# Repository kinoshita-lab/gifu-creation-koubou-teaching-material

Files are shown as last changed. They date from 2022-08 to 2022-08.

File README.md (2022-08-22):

# gifu-creation-koubou-teaching-material
こちらは、オンラインワークショップ 岐阜クリエーション工房2022 2. 自分の電子楽器をデザインしよう！
https://sites.google.com/iamas.ac.jp/gifu-creation-workshop/2022?authuser=0#h.r4l3rx4b2rmy
で配布した教材のリポジトリです。

## 教材基板ハードウェアの設計図(pdf)
- [ベースボードの回路図](https://github.com/kinoshita-lab/gifu-creation-koubou-teaching-material/blob/main/hardware/base-pcb/gifu-creation-koubou-teaching-material-schematics.pdf)
- [ベースボードの基板](https://github.com/kinoshita-lab/gifu-creation-koubou-teaching-material/blob/main/hardware/base-pcb/gifu-creation-koubou-teaching-material-pcb.pdf)

- [フィルターの回路図](https://github.com/kinoshita-lab/gifu-creation-koubou-teaching-material/blob/main/hardware/vcf-13700/vcf-13700-schematics.pdf)
- [フィルターの基板](https://github.com/kinoshita-lab/gifu-creation-koubou-teaching-material/blob/main/hardware/vcf-13700/vcf-13700-pcb.pdf)

- [ディレイの回路図](https://github.com/kinoshita-lab/gifu-creation-koubou-teaching-material/blob/main/hardware/PT2399delay/PT2399delay-schematics.pdf)
- [ディレイの基板](https://github.com/kinoshita-lab/gifu-creation-koubou-teaching-material/blob/main/hardware/PT2399delay/PT2399delay-pcb.pdf)

## マイコンのソフト
[Platform IO](https://platformio.org/) という開発環境を使っています。
- [ライブラリを含んだ全体](https://github.com/kinoshita-lab/gifu-creation-koubou-teaching-material/tree/main/software/gifu-creation-koubou-teathing-material-esp32)
- [一番重要な内容が書いてあるファイル](https://github.com/kinoshita-lab/gifu-creation-koubou-teaching-material/blob/main/software/gifu-creation-koubou-teathing-material-esp32/src/main.cpp)

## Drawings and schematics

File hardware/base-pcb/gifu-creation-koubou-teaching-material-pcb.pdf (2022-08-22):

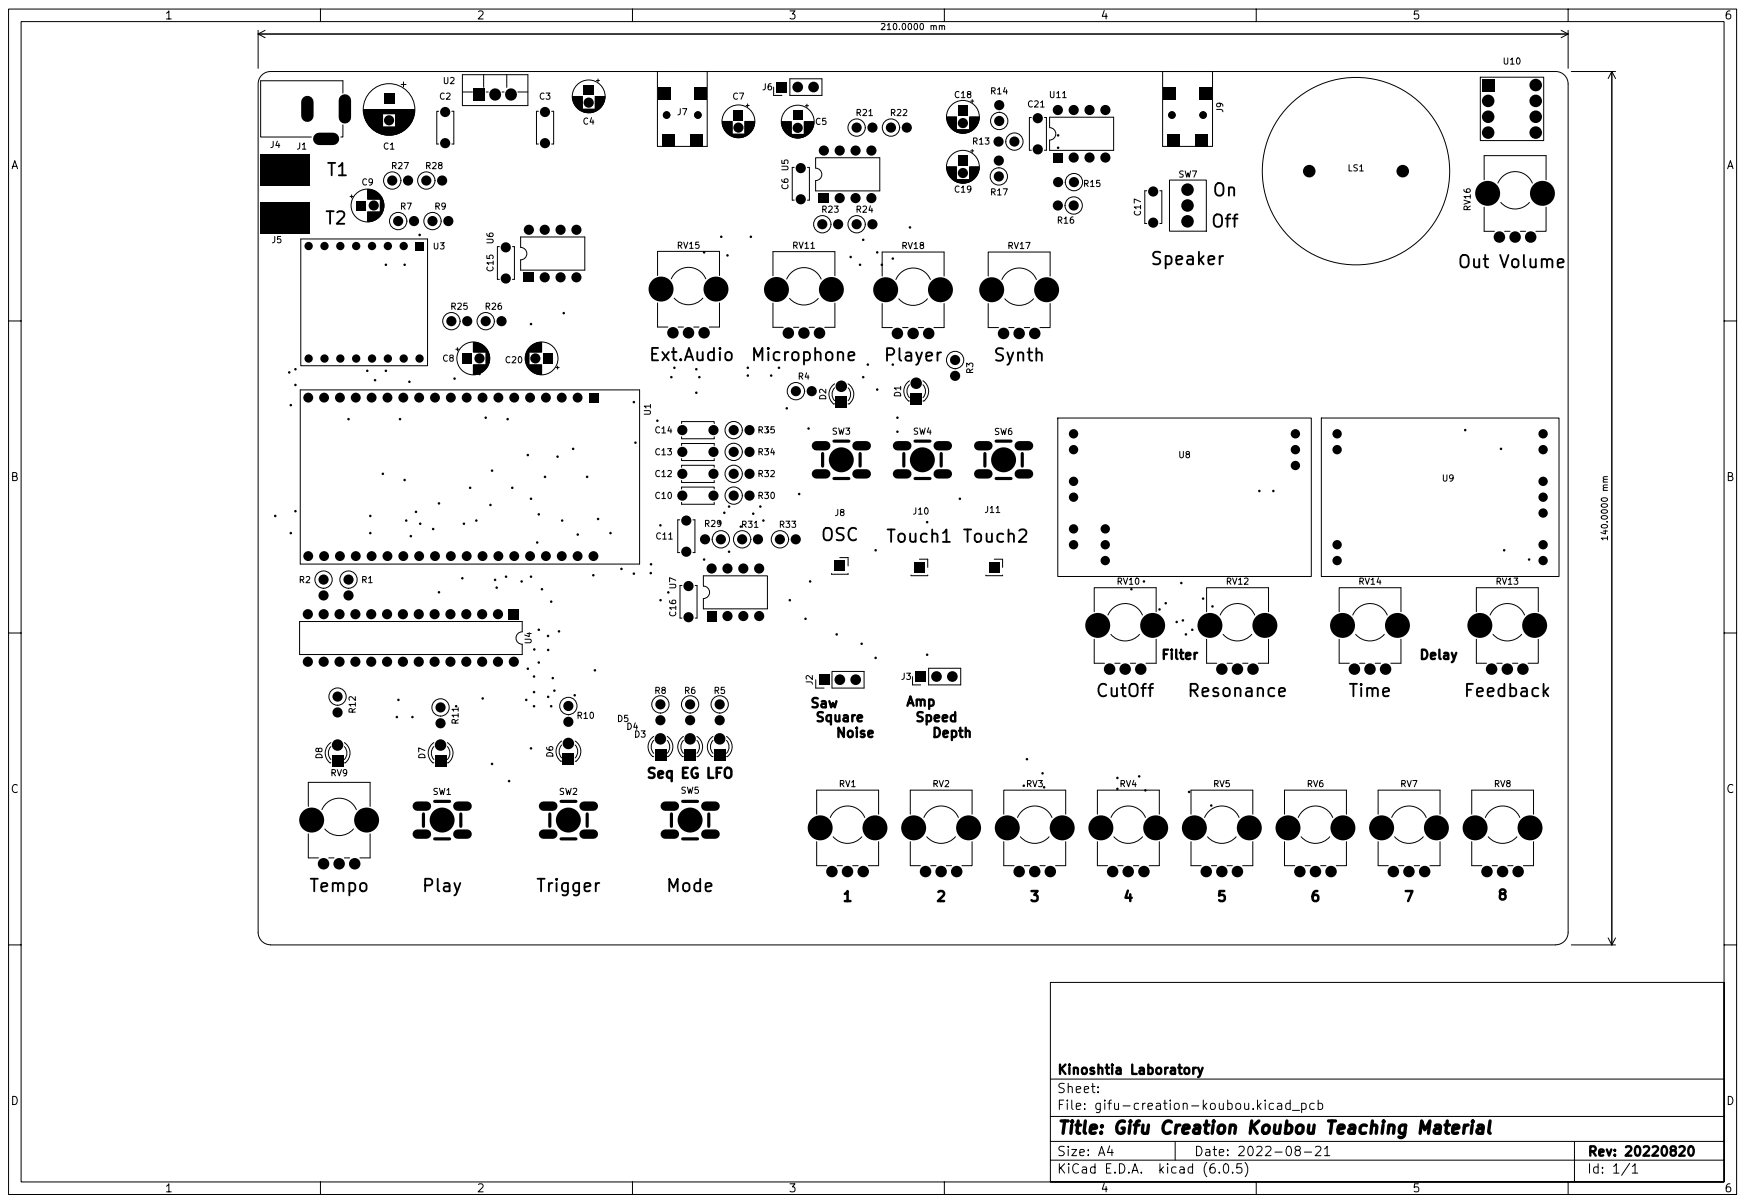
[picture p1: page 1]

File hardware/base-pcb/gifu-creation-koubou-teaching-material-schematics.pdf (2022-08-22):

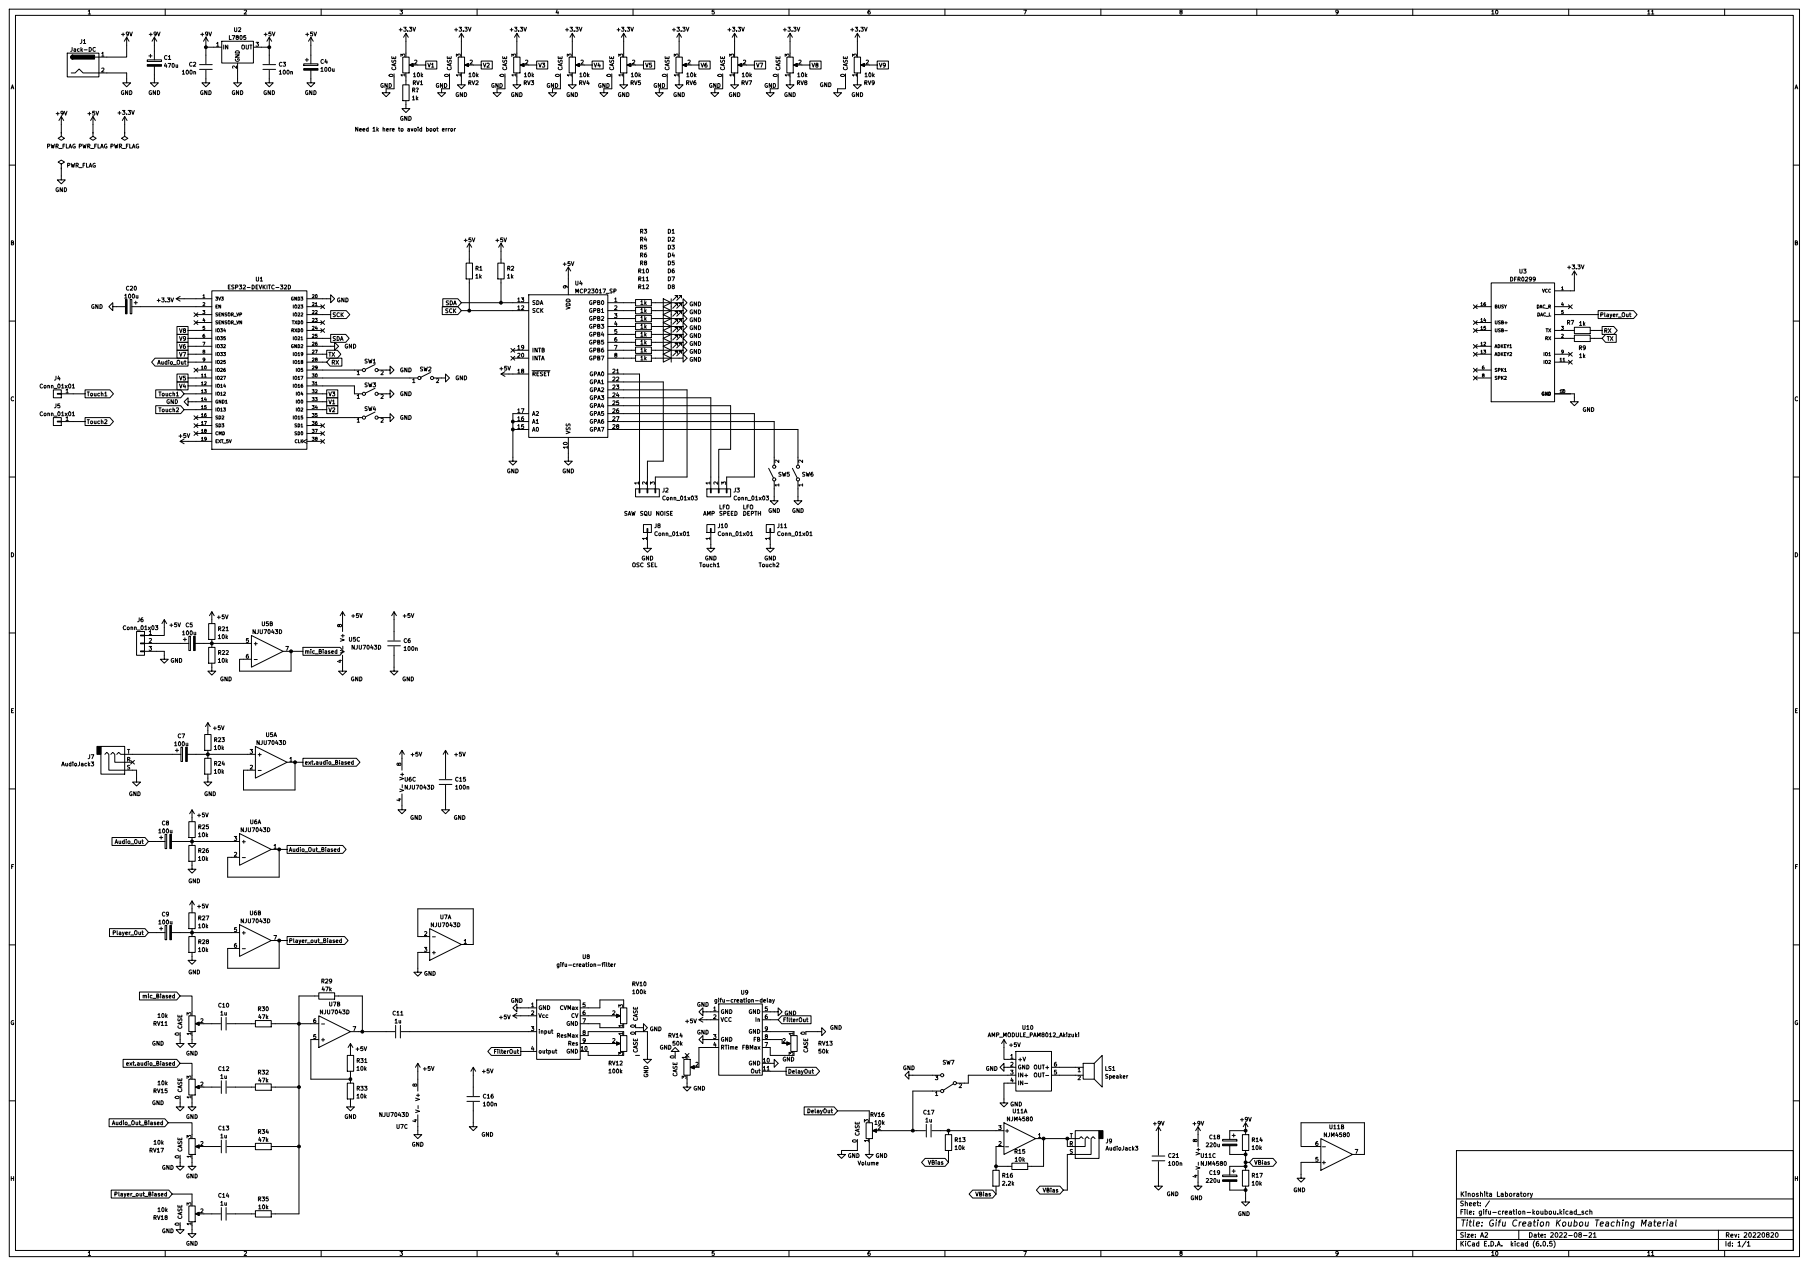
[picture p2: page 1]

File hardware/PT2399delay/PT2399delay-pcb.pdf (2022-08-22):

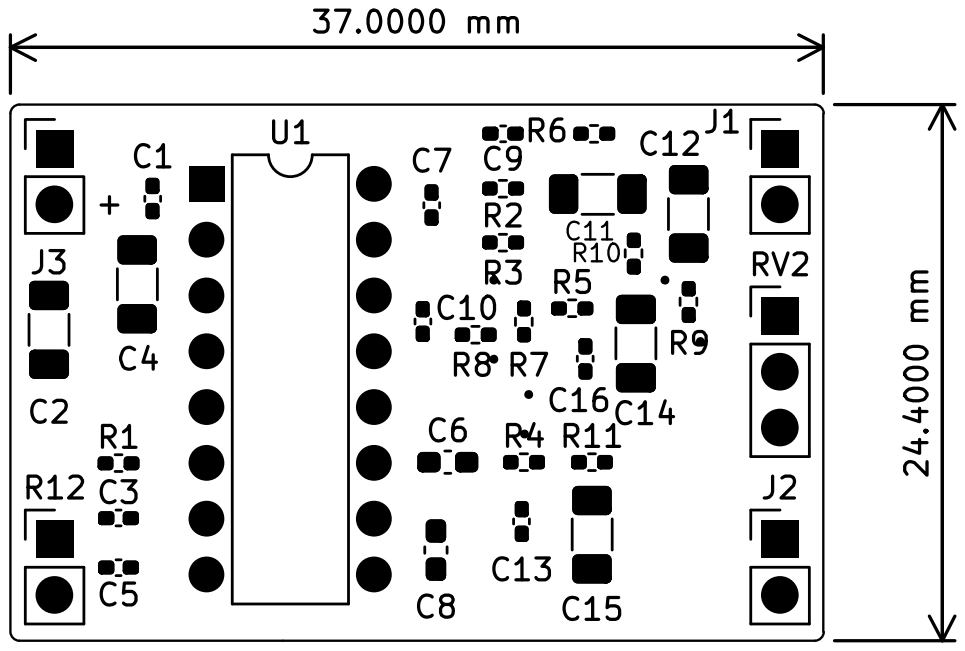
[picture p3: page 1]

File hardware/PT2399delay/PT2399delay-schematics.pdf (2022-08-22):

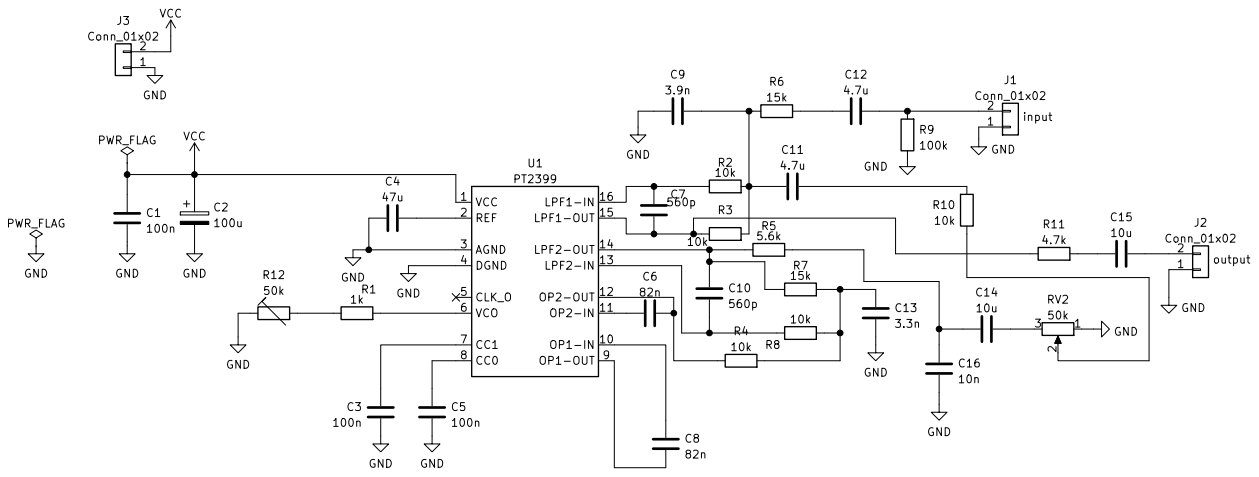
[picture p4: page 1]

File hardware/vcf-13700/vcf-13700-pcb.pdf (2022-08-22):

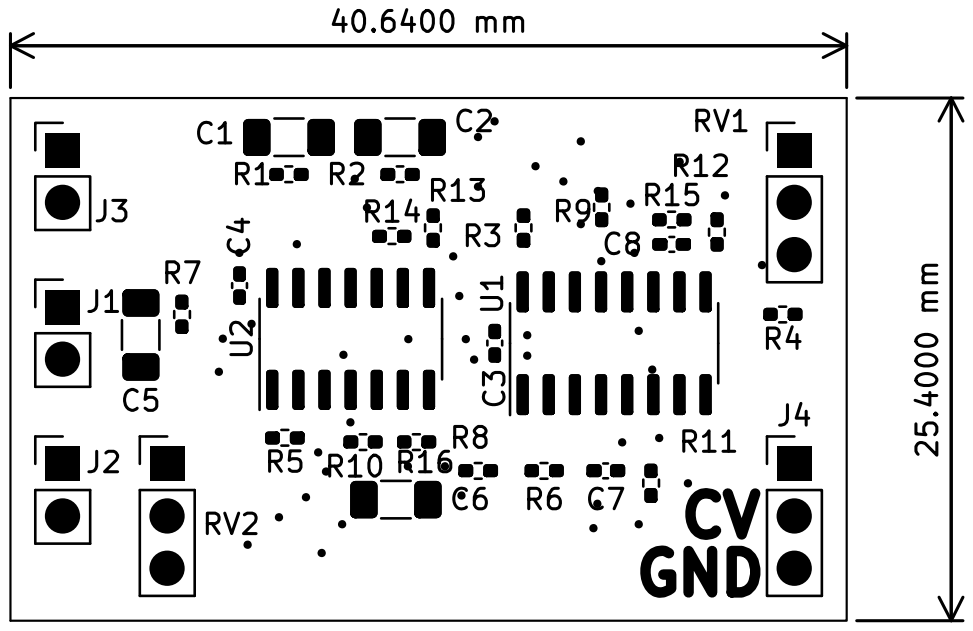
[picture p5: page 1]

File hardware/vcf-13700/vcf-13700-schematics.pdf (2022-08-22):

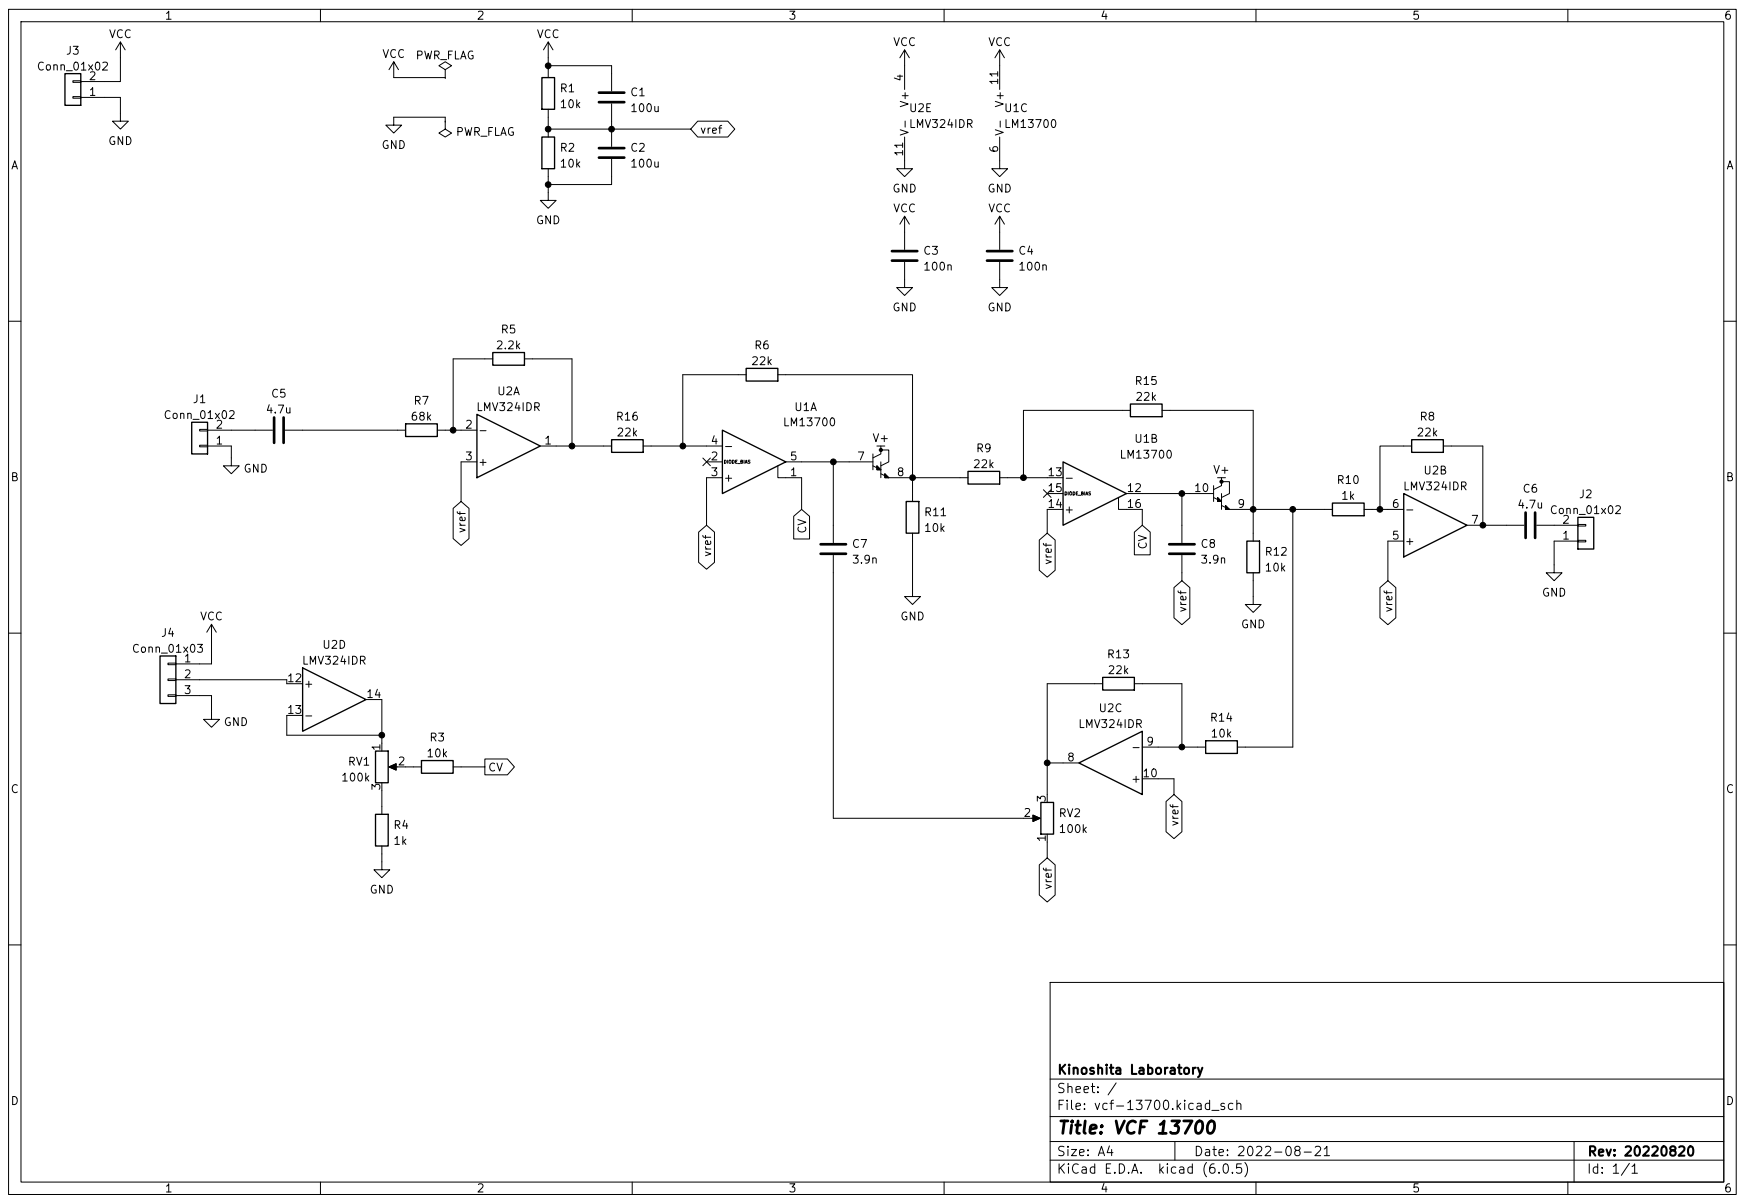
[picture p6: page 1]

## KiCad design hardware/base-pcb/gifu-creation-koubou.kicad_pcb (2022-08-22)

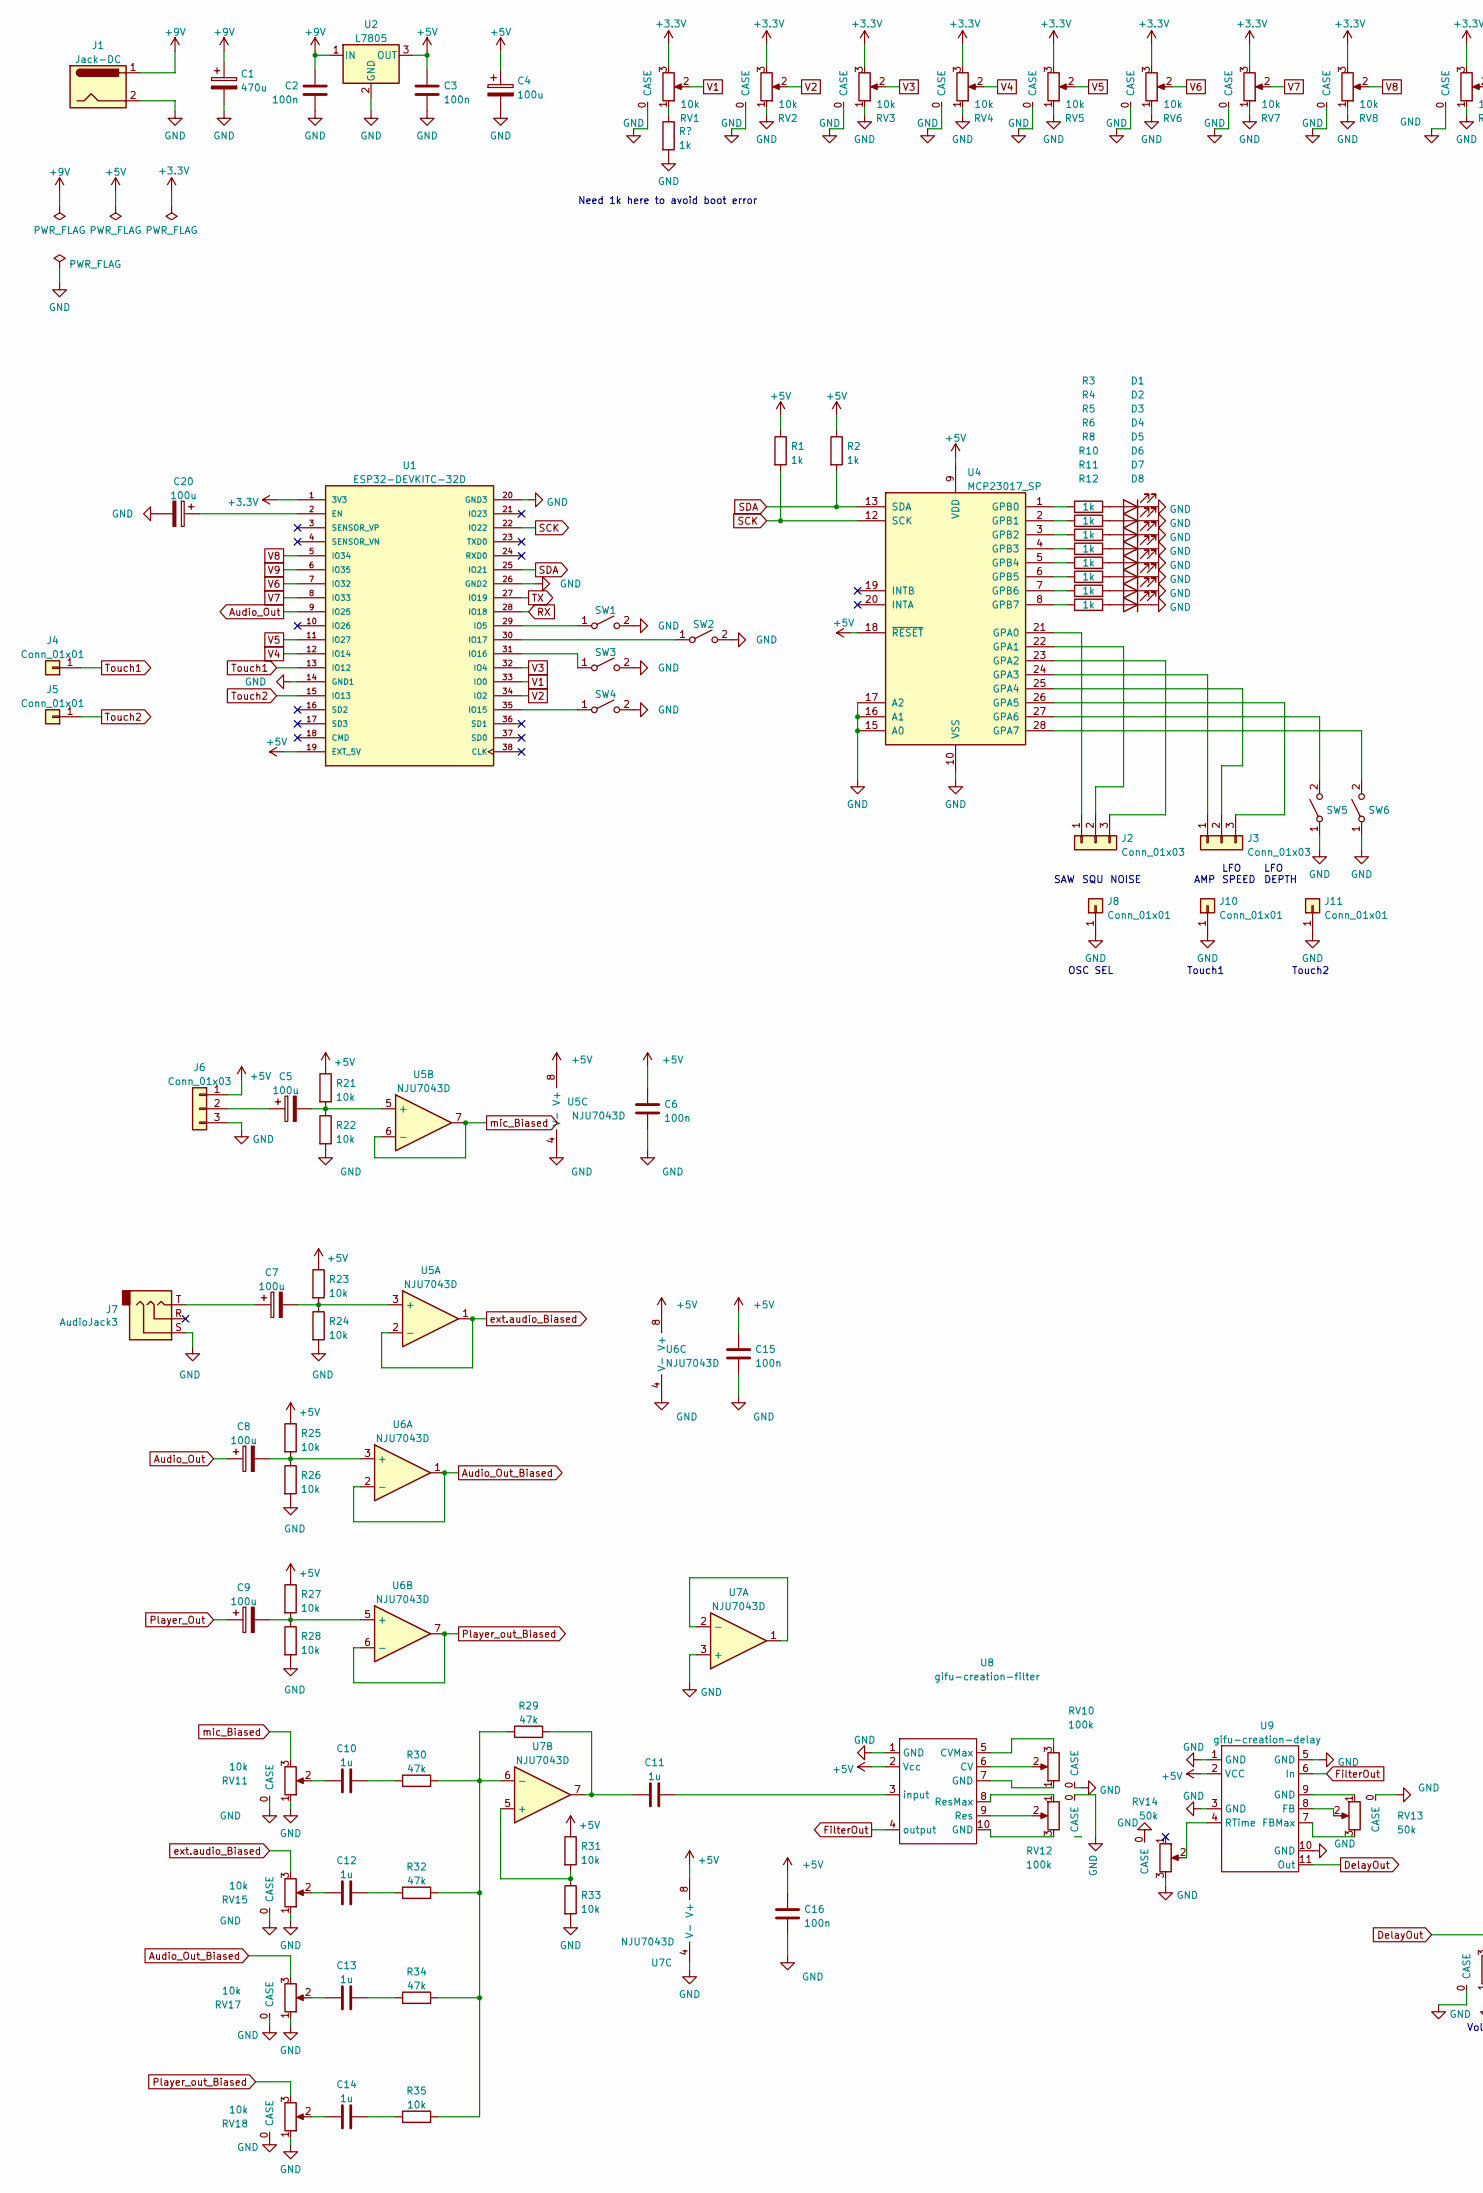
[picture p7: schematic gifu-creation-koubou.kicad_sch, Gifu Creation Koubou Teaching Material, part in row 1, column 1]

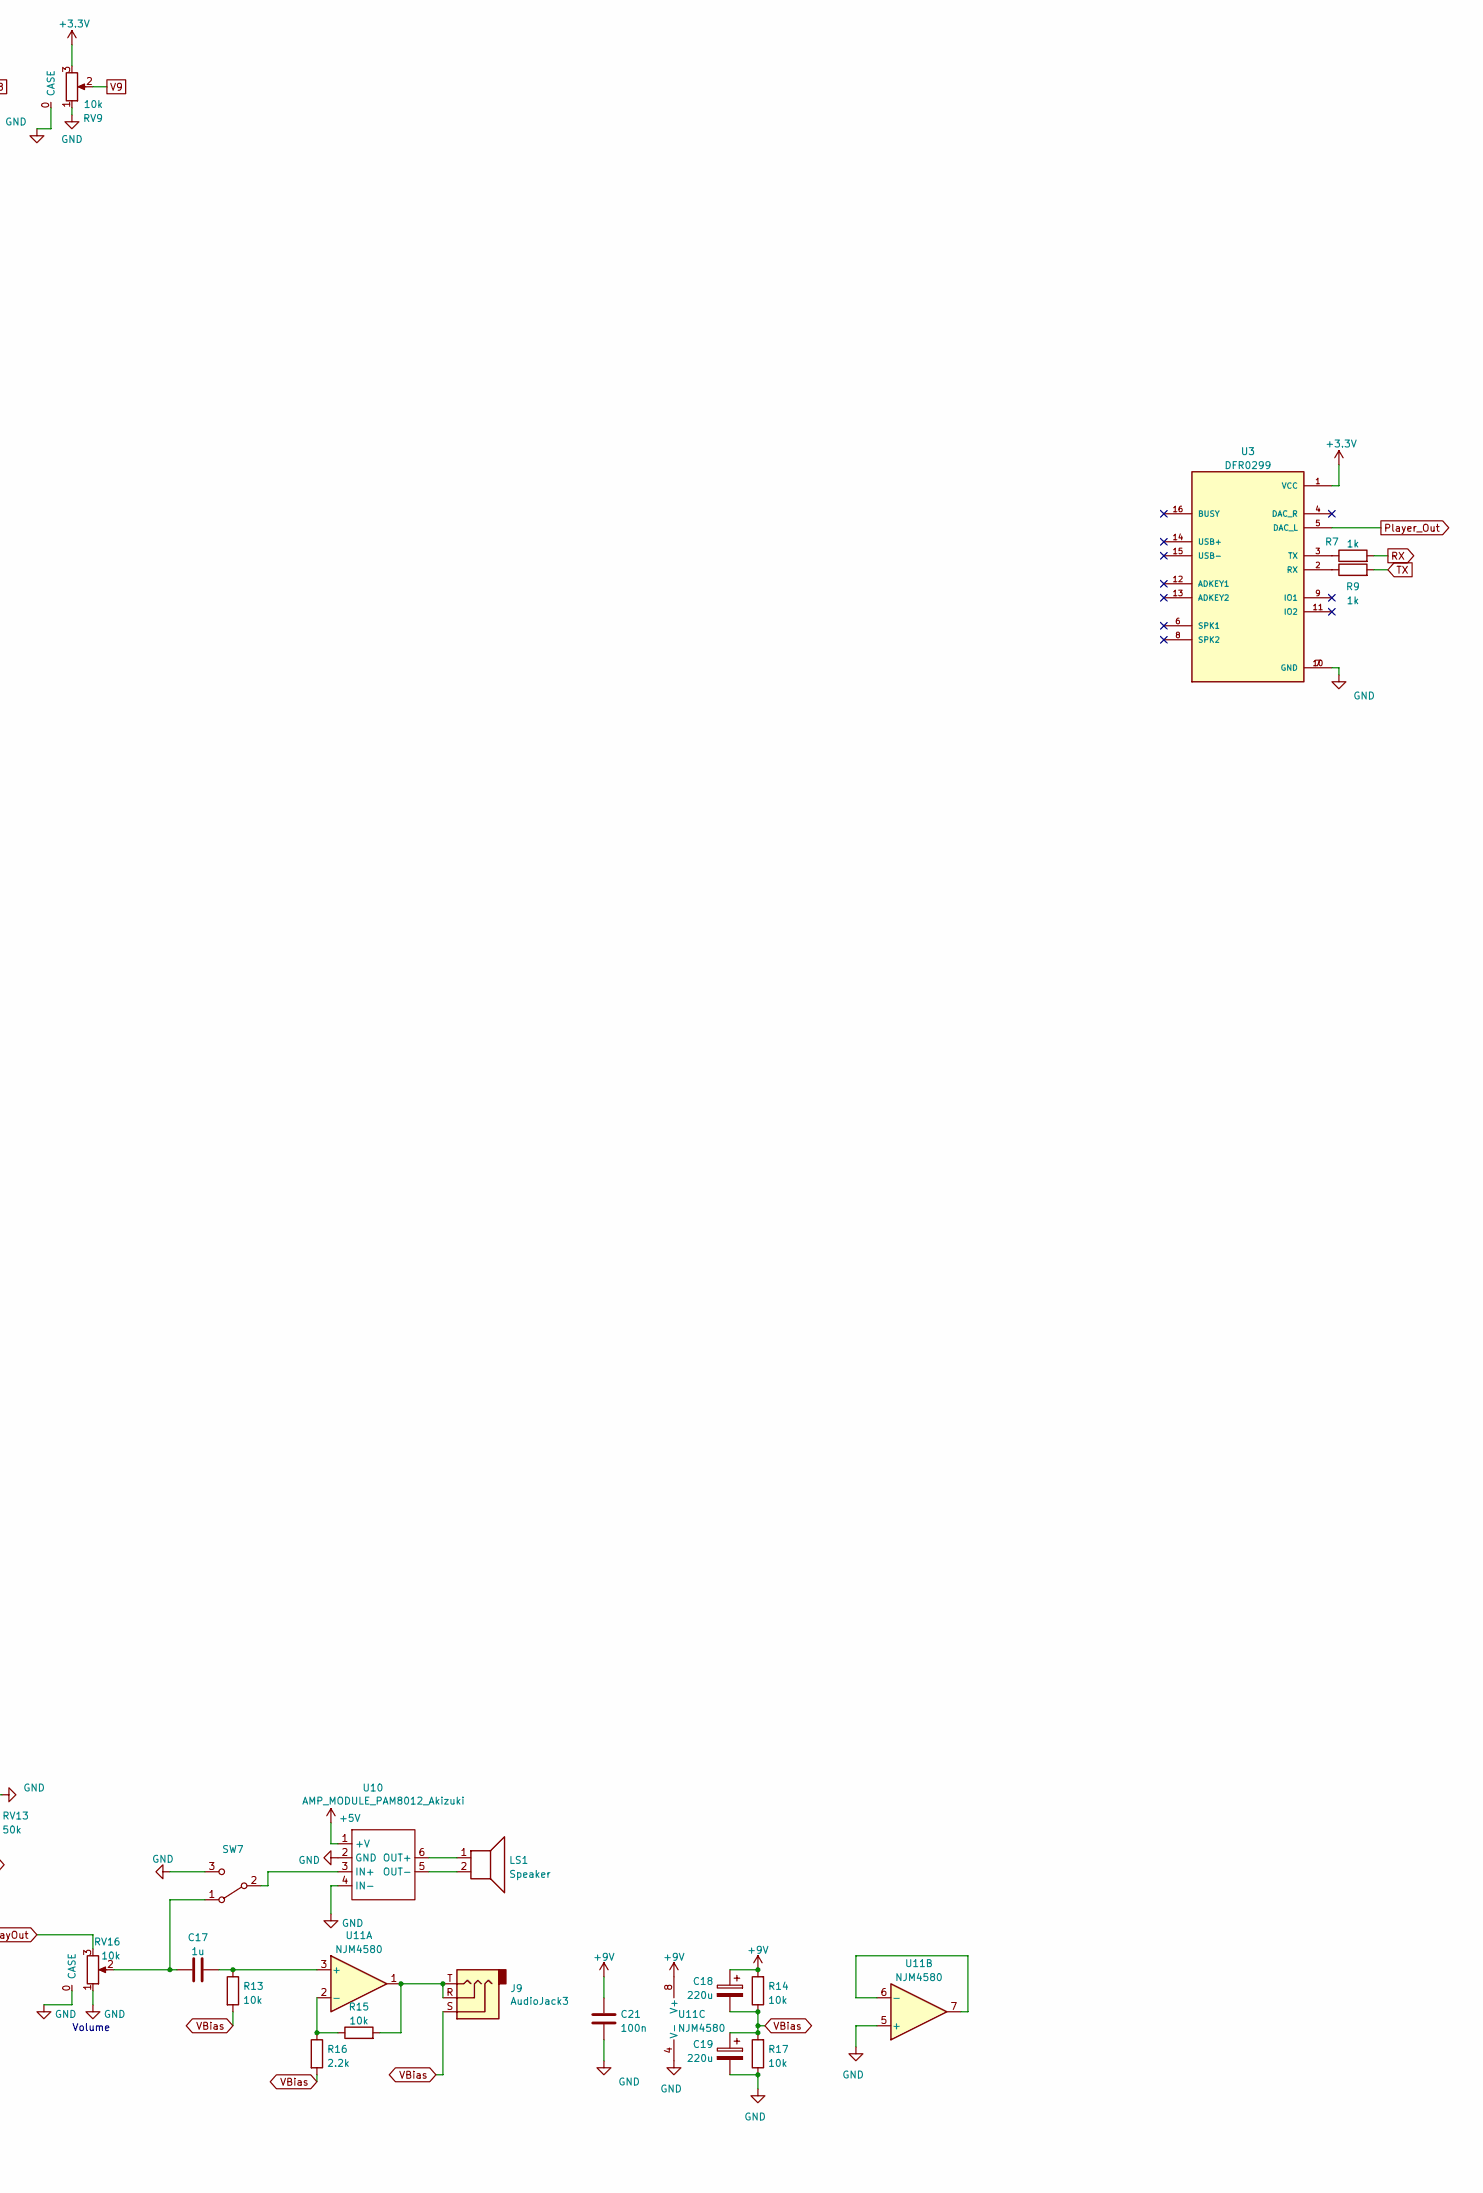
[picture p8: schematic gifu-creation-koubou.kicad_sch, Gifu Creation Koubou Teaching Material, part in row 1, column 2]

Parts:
C1: 470u; CP_Radial_D8.0mm_P3.50mm
C2, C3, C6, C15, C16, C21: 100n; C_Disc_D5.0mm_W2.5mm_P5.00mm
C4, C5, C7, C8, C9, C20: 100u; CP_Radial_D5.0mm_P2.00mm
C10, C11, C12, C13, C14, C17: 1u; C_Disc_D5.0mm_W2.5mm_P5.00mm
C18, C19: 220u; CP_Radial_D5.0mm_P2.00mm
D1, D2, D3, D4, D5, D6, D7, D8: LED; LED_D3.0mm
J1: Jack-DC; DCJ3P-14.2X11.0X9.0MM
J2, J3, J6: Conn_01x03; PinHeader_1x03_P2.54mm_Vertical
J4, J5: Conn_01x01; touch_electrode
J7, J9: AudioJack3; 3.5mm_Stereo_TRS_PJ-3210-4A_and_ST-005-G; LCSC C136686
J8, J10, J11: Conn_01x01; PinSocket_1x01_P2.54mm_Vertical
LS1: Speaker; Speaker_UGSM30B-8-01
R1, R2, R3, R4, R5, R6, R7, R8, R9, R10, R11, R12: 1k; R_Axial_DIN0207_L6.3mm_D2.5mm_P2.54mm_Vertical
R13, R14, R15, R17, R21, R22, R23, R24, R25, R26, R27, R28, R31, R33, R35: 10k; R_Axial_DIN0207_L6.3mm_D2.5mm_P2.54mm_Vertical
R16: 2.2k; R_Axial_DIN0207_L6.3mm_D2.5mm_P2.54mm_Vertical
R29, R30, R32, R34: 47k; R_Axial_DIN0207_L6.3mm_D2.5mm_P2.54mm_Vertical
RV1, RV2, RV3, RV4, RV5, RV6, RV7, RV8, RV9, RV11, RV15, RV16, RV17, RV18: 10k; Potentiometer_Alps_RK09K_Horizontal_CORRECTED
RV10, RV12: 100k; Potentiometer_Alps_RK09K_Horizontal_CORRECTED
RV13, RV14: 50k; Potentiometer_Alps_RK09K_Horizontal_CORRECTED
SW1, SW2, SW3, SW4, SW5, SW6: SW_SPST; SW_Tactile_6mm_x_6mm_Futsuuno_Akizuki_nadoniaruyatsu
SW7: SW_SPDT; Switch_Toggle_PCB_Mount_Akizuki_2MS1-T1-B4-M2-Q-E
U1: ESP32-DEVKITC-32D; MODULE_ESP32-DEVKITC-32D; PARTREV 4
U2: L7805; TO-220F-3_Vertical
U3: DFR0299; MODULE_DFR0299
U4: MCP23017_SP; DIP-28_W7.62mm
U5, U6, U7: NJU7043D; DIP-8_W7.62mm
U8: gifu-creation-filter; filter_13700
U9: gifu-creation-delay; delay
U10: AMP_MODULE_PAM8012_Akizuki; AMP_Module_PAM8012_Akizuki
U11: NJM4580; DIP-8_W7.62mm

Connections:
+3V3: RV1.3, RV2.3, RV3.3, RV4.3, RV5.3, RV6.3, RV7.3, RV8.3, RV9.3, U1.1 (3V3), U3.1 (VCC)
+5V: C3.1, C4.1, C6.1, C15.1, C16.1, J6.1, R1.1, R2.1, R21.1, R23.1, R25.1, R27.1, R31.1, U1.19 (EXT_5V), U2.3 (OUT), U4.9 (VDD), U4.18 (~RESET), U5.8 (V+), U6.8 (V+), U7.8 (V+), U8.2 (Vcc), U9.2 (VCC), U10.1 (+V)
+9V: C1.1, C2.1, C18.1, C21.1, J1.1, R14.2, U2.1 (IN), U11.8 (V+)
Audio_Out: C8.1, U1.9 (IO25)
Audio_Out_Biased: RV17.3, U6.1, U6.2 (-)
DelayOut: RV16.3, U9.11 (Out)
FilterOut: U8.4 (output), U9.6 (In)
GND: C1.2, C2.2, C3.2, C4.2, C6.2, C15.2, C16.2, C19.2, C20.2, C21.2, D1.1 (K), D2.1 (K), D3.1 (K), D4.1 (K), D5.1 (K), D6.1 (K), D7.1 (K), D8.1 (K), J1.2, J6.3, J7.S, J8.1, J10.1, J11.1, R17.1, R22.2, R24.2, R26.2, R28.2, R33.2, RV1.0 (CASE), RV1.1, RV2.0 (CASE), RV2.1, RV3.0 (CASE), RV3.1, RV4.0 (CASE), RV4.1, RV5.0 (CASE), RV5.1, RV6.0 (CASE), RV6.1, RV7.0 (CASE), RV7.1, RV8.0 (CASE), RV8.1, RV9.0 (CASE), RV9.1, RV10.0 (CASE), RV11.0 (CASE), RV11.1, RV12.0 (CASE), RV13.0 (CASE), RV14.0 (CASE), RV14.3, RV15.0 (CASE), RV15.1, RV16.0 (CASE), RV16.1, RV17.0 (CASE), RV17.1, RV18.0 (CASE), RV18.1, SW1.2 (B), SW2.2 (B), SW3.2 (B), SW4.2 (B), SW5.1 (A), SW6.1 (A), SW7.3 (C), U1.14 (GND1), U1.20 (GND3), U1.26 (GND2), U2.2 (GND), U3.7 (GND), U3.10 (GND), U4.10 (VSS), U4.15 (A0), U4.16 (A1), U4.17 (A2), U5.4 (V-), U6.4 (V-), U7.3 (+), U7.4 (V-), U8.1 (GND), U9.1 (GND), U9.3 (GND), U9.5 (GND), U9.10 (GND), U10.2 (GND), U10.4 (IN-), U11.4 (V-), U11.5 (+)
unnamed: C5.1, J6.2
unnamed: C5.2, R21.2, R22.1, U5.5 (+)
unnamed: C7.1, J7.T
unnamed: C7.2, R23.2, R24.1, U5.3 (+)
unnamed: C8.2, R25.2, R26.1, U6.3 (+)
unnamed: C9.2, R27.2, R28.1, U6.5 (+)
unnamed: C10.1, RV11.2
unnamed: C10.2, R30.1
unnamed: C11.1, R29.2, U7.7
unnamed: C11.2, U8.3 (input)
unnamed: C12.1, RV15.2
unnamed: C12.2, R32.1
unnamed: C13.1, RV17.2
unnamed: C13.2, R34.1
unnamed: C14.1, RV18.2
unnamed: C14.2, R35.1
unnamed: C17.1, RV16.2, SW7.1 (A)
unnamed: C17.2, R13.1, U11.3 (+)
unnamed: D1.2 (A), R3.2
unnamed: D2.2 (A), R4.2
unnamed: D3.2 (A), R5.2
unnamed: D4.2 (A), R6.2
unnamed: D5.2 (A), R8.2
unnamed: D6.2 (A), R10.2
unnamed: D7.2 (A), R11.2
unnamed: D8.2 (A), R12.2
unnamed: J2.1, U4.21 (GPA0)
unnamed: J2.2, U4.22 (GPA1)
unnamed: J2.3, U4.23 (GPA2)
unnamed: J3.1, U4.24 (GPA3)
unnamed: J3.2, U4.25 (GPA4)
unnamed: J3.3, U4.26 (GPA5)
unnamed: J9.R, J9.T, R15.2, U11.1
unnamed: LS1.1, U10.6 (OUT+)
unnamed: LS1.2, U10.5 (OUT-)
unnamed: R3.1, U4.1 (GPB0)
unnamed: R4.1, U4.2 (GPB1)
unnamed: R5.1, U4.3 (GPB2)
unnamed: R6.1, U4.4 (GPB3)
unnamed: R7.1, U3.3 (TX)
unnamed: R8.1, U4.5 (GPB4)
unnamed: R9.1, U3.2 (RX)
unnamed: R10.1, U4.6 (GPB5)
unnamed: R11.1, U4.7 (GPB6)
unnamed: R12.1, U4.8 (GPB7)
unnamed: R15.1, R16.1, U11.2 (-)
unnamed: R29.1, R30.2, R32.2, R34.2, R35.2, U7.6 (-)
unnamed: R31.2, R33.1, U7.5 (+)
unnamed: RV10.1, U8.7 (GND)
unnamed: RV10.2, U8.6 (CV)
unnamed: RV10.3, U8.5 (CVMax)
unnamed: RV12.1, U8.8 (ResMax)
unnamed: RV12.2, U8.9 (Res)
unnamed: RV12.3, U8.10 (GND)
unnamed: RV13.1, U9.9 (GND)
unnamed: RV13.2, U9.8 (FB)
unnamed: RV13.3, U9.7 (FBMax)
unnamed: RV14.2, U9.4 (RTime)
unnamed: SW1.1 (A), U1.29 (IO5)
unnamed: SW2.1 (A), U1.30 (IO17)
unnamed: SW3.1 (A), U1.31 (IO16)
unnamed: SW4.1 (A), U1.35 (IO15)
unnamed: SW5.2 (B), U4.27 (GPA6)
unnamed: SW6.2 (B), U4.28 (GPA7)
unnamed: SW7.2 (B), U10.3 (IN+)
unnamed: C20.1, U1.2 (EN)
unnamed: U7.1, U7.2 (-)
unnamed: U11.6 (-), U11.7
Player_Out: C9.1, U3.5 (DAC_L)
Player_out_Biased: RV18.3, U6.6 (-), U6.7
RX: R7.2, U1.28 (IO18)
SCK: R1.2, U1.22 (IO22), U4.12 (SCK)
SDA: R2.2, U1.25 (IO21), U4.13 (SDA)
TX: R9.2, U1.27 (IO19)
Touch1: J4.1, U1.13 (IO12)
Touch2: J5.1, U1.15 (IO13)
V1: RV1.2, U1.33 (IO0)
V2: RV2.2, U1.34 (IO2)
V3: RV3.2, U1.32 (IO4)
V4: RV4.2, U1.12 (IO14)
V5: RV5.2, U1.11 (IO27)
V6: RV6.2, U1.7 (IO32)
V7: RV7.2, U1.8 (IO33)
V8: RV8.2, U1.5 (IO34)
V9: RV9.2, U1.6 (IO35)
VBias: C18.2, C19.1, J9.S, R13.2, R14.1, R16.2, R17.2
ext.audio_Biased: RV15.3, U5.1, U5.2 (-)
mic_Biased: RV11.3, U5.6 (-), U5.7

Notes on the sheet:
AMP
LFO DEPTH
SQU
OSC SEL
Volume
Touch1
Touch2
Need 1k here to avoid boot error
SAW
NOISE
LFO SPEED

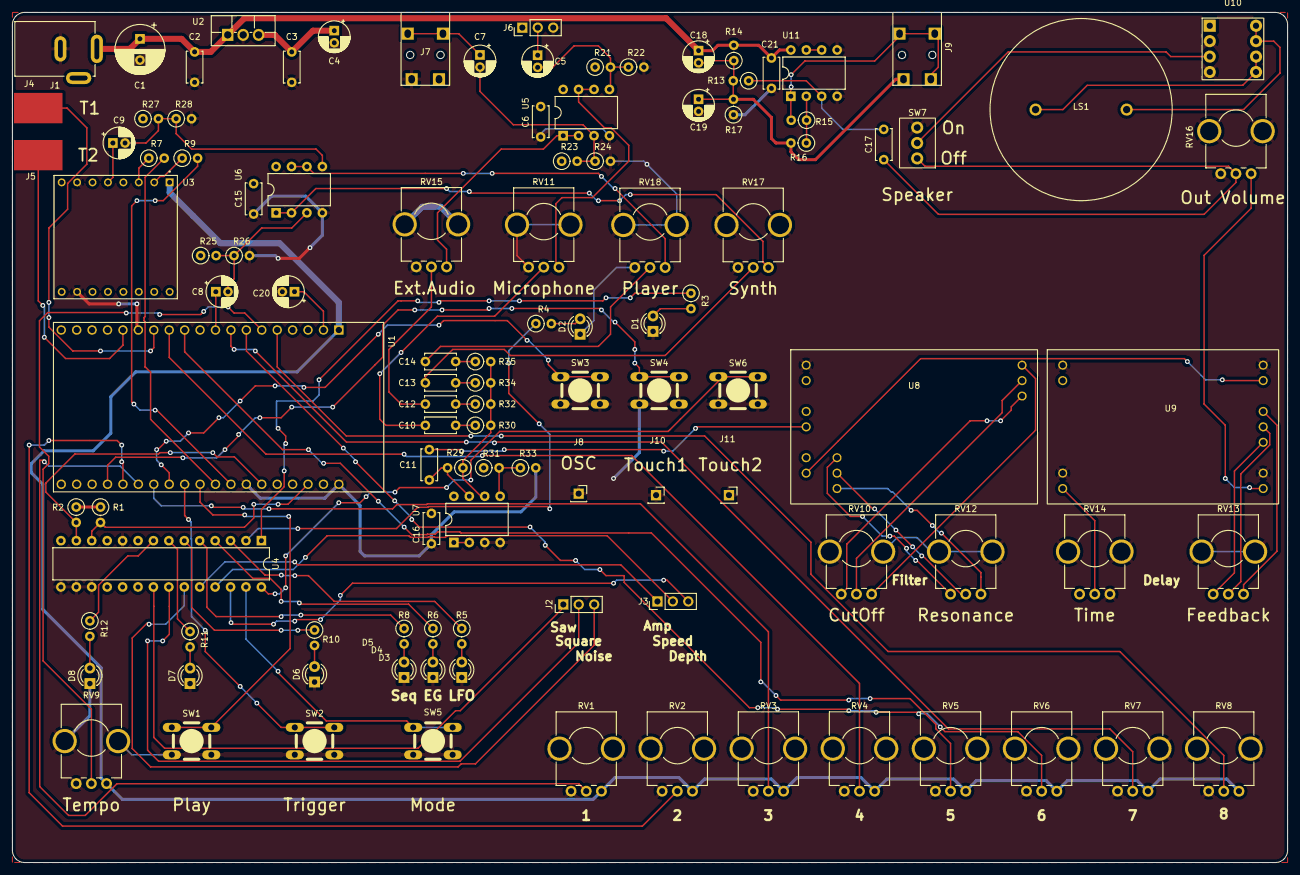
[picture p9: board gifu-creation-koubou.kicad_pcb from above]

Board: 2 copper layers, 210.0 x 140.0 mm, 109 parts (0 on the bottom side), 96 nets.

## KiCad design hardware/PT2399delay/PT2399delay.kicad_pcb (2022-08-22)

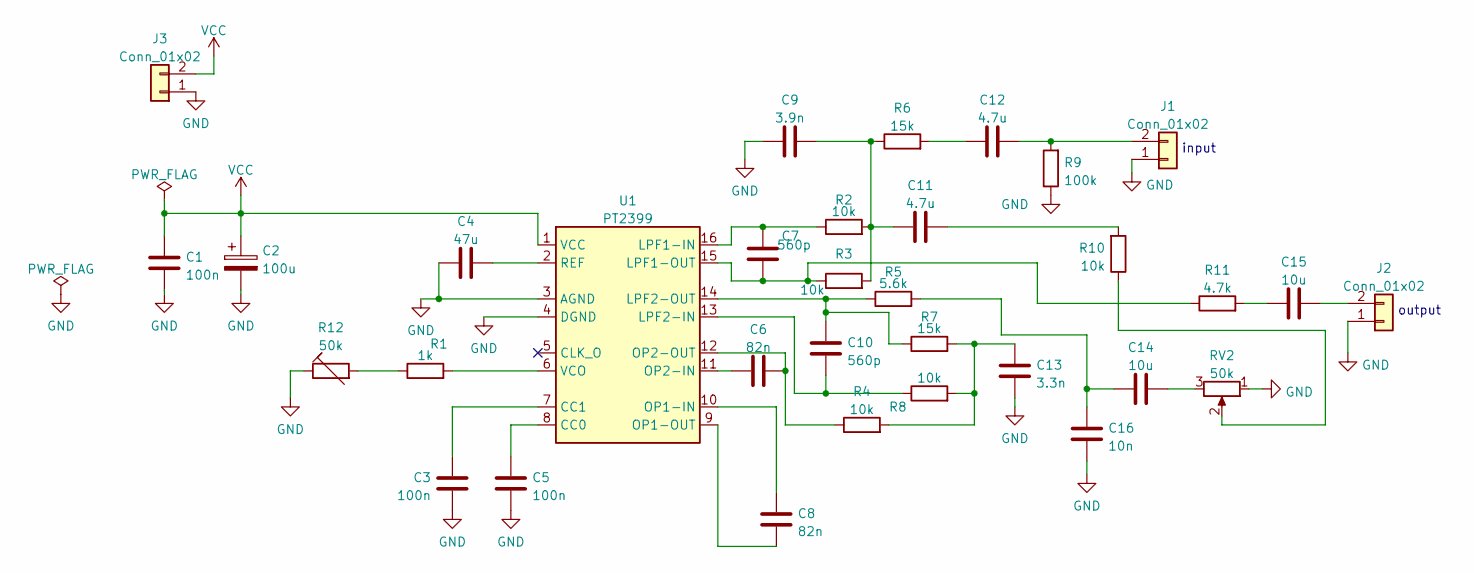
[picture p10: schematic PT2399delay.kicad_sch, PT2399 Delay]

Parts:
C1, C3, C5: 100n; C_0402_1005Metric_Pad0.74x0.62mm_HandSolder; LCSC C1525
C2: 100u; C_1206_3216Metric_Pad1.33x1.80mm_HandSolder; LCSC C312983
C4: 47u; C_1206_3216Metric_Pad1.33x1.80mm_HandSolder; LCSC C403725
C6, C8: 82n; C_0603_1608Metric_Pad1.08x0.95mm_HandSolder; LCSC C1951
C7, C10: 560p; C_0402_1005Metric_Pad0.74x0.62mm_HandSolder; LCSC C1539
C9: 3.9n; C_0402_1005Metric_Pad0.74x0.62mm_HandSolder; LCSC C45188
C11, C12: 4.7u; C_1206_3216Metric_Pad1.33x1.80mm_HandSolder; LCSC C29823
C13: 3.3n; C_0402_1005Metric_Pad0.74x0.62mm_HandSolder; LCSC C26404
C14: 10u; C_1206_3216Metric_Pad1.33x1.80mm_HandSolder; LCSC C13585
C15: 10u; C_1206_3216Metric_Pad1.33x1.80mm_HandSolder; LCSC C13585Copy
C16: 10n; C_0402_1005Metric_Pad0.74x0.62mm_HandSolder; LCSC C15195
J1, J2, J3: Conn_01x02; PinHeader_1x02_P2.54mm_Vertical
R1: 1k; R_0402_1005Metric_Pad0.72x0.64mm_HandSolder; LCSC C144789
R2, R3, R4, R8, R10: 10k; R_0402_1005Metric_Pad0.72x0.64mm_HandSolder; LCSC C25744
R5: 5.6k; R_0402_1005Metric_Pad0.72x0.64mm_HandSolder; LCSC C25908
R6, R7: 15k; R_0402_1005Metric_Pad0.72x0.64mm_HandSolder; LCSC C25756
R9: 100k; R_0402_1005Metric_Pad0.72x0.64mm_HandSolder; LCSC C25741
R11: 4.7k; R_0402_1005Metric_Pad0.72x0.64mm_HandSolder; LCSC C25900
R12: 50k; PinHeader_1x02_P2.54mm_Vertical
RV2: 50k; PinHeader_1x03_P2.54mm_Vertical
U1: PT2399; DIP-16_W7.62mm; LCSC C84963

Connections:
GND: C1.1, C2.2, C3.1, C4.1, C5.1, C9.2, C13.1, C16.2, J1.1, J2.1, J3.1, R9.1, R12.1, RV2.1, U1.3 (AGND), U1.4 (DGND)
unnamed: C3.2, U1.7 (CC1)
unnamed: C4.2, U1.2 (REF)
unnamed: C5.2, U1.8 (CC0)
unnamed: C6.1, U1.11 (OP2-IN)
unnamed: C6.2, R4.1, U1.12 (OP2-OUT)
unnamed: C7.1, R3.1, R11.1, U1.15 (LPF1-OUT)
unnamed: C7.2, R2.1, U1.16 (LPF1-IN)
unnamed: C8.1, U1.9 (OP1-OUT)
unnamed: C8.2, U1.10 (OP1-IN)
unnamed: C10.1, R8.1, U1.13 (LPF2-IN)
unnamed: C10.2, R5.1, R7.1, U1.14 (LPF2-OUT)
unnamed: C11.1, R10.2
unnamed: C9.1, C11.2, R2.2, R3.2, R6.1
unnamed: C12.1, J1.2, R9.2
unnamed: C12.2, R6.2
unnamed: C13.2, R4.2, R7.2, R8.2
unnamed: C14.1, RV2.3
unnamed: C14.2, C16.1, R5.2
unnamed: C15.1, J2.2
unnamed: C15.2, R11.2
unnamed: R1.1, R12.2
unnamed: R1.2, U1.6 (VCO)
unnamed: R10.1, RV2.2
VCC: C1.2, C2.1, J3.2, U1.1 (VCC)

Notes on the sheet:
input
output

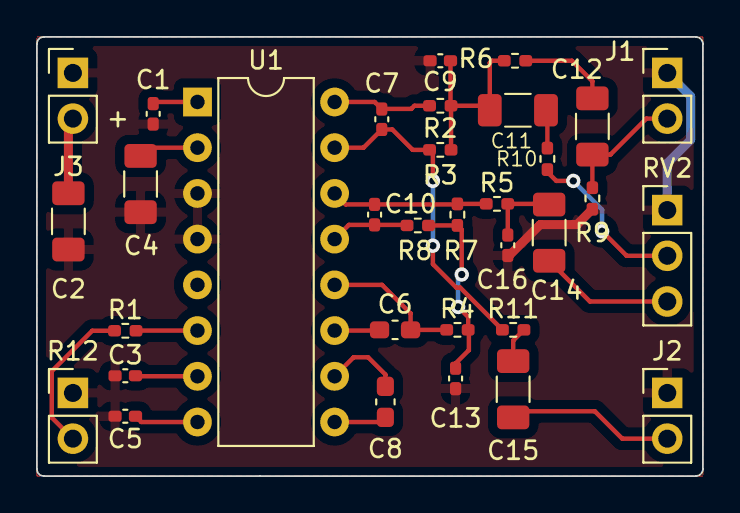
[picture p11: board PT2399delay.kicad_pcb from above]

Board: 2 copper layers, 37.0 x 24.4 mm, 33 parts (0 on the bottom side), 25 nets.

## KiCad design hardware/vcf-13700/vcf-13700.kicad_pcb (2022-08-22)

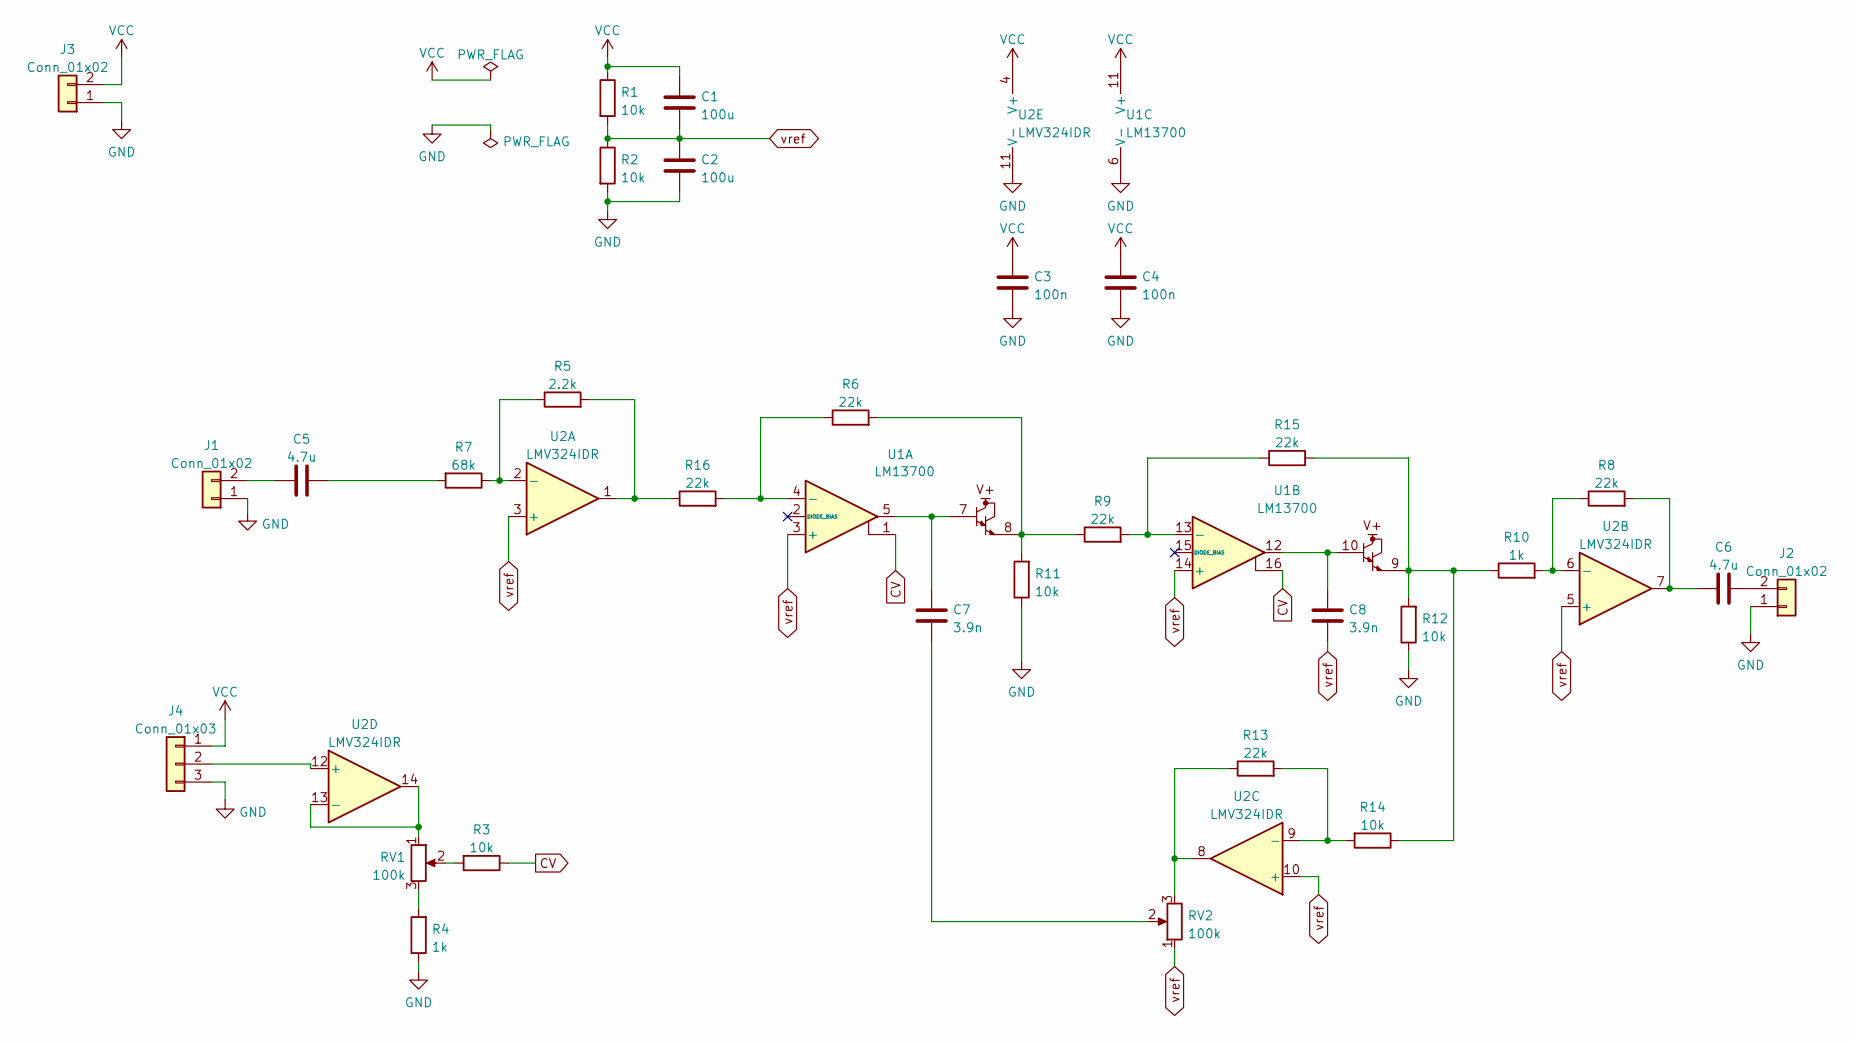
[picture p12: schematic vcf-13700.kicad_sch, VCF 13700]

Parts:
C1, C2: 100u; C_1206_3216Metric_Pad1.33x1.80mm_HandSolder; LCSC C15008
C3, C4: 100n; C_0402_1005Metric_Pad0.74x0.62mm_HandSolder; LCSC C1525
C5, C6: 4.7u; C_1206_3216Metric_Pad1.33x1.80mm_HandSolder; LCSC C29823
C7, C8: 3.9n; C_0402_1005Metric_Pad0.74x0.62mm_HandSolder; LCSC C45188
J1, J2, J3: Conn_01x02; PinHeader_1x02_P2.54mm_Vertical
J4: Conn_01x03; PinHeader_1x03_P2.54mm_Vertical
R1, R2, R3, R11, R12, R14: 10k; R_0402_1005Metric_Pad0.72x0.64mm_HandSolder; LCSC C25744
R4, R10: 1k; R_0402_1005Metric_Pad0.72x0.64mm_HandSolder; LCSC C144789
R5: 2.2k; R_0402_1005Metric_Pad0.72x0.64mm_HandSolder; LCSC C25879
R6, R8, R9, R13, R15, R16: 22k; R_0402_1005Metric_Pad0.72x0.64mm_HandSolder; LCSC C25768
R7: 68k; R_0402_1005Metric_Pad0.72x0.64mm_HandSolder; LCSC C36871
RV1, RV2: 100k; PinHeader_1x03_P2.54mm_Vertical
U1: LM13700; SOP-16_3.9x9.9mm_P1.27mm; LCSC C174050
U2: LMV324IDR; SO-14_3.9x8.65mm_P1.27mm; LCSC C7974

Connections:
CV: R3.1, U1.1, U1.16
GND: C2.2, C3.1, C4.1, J3.1, J4.3, R2.2, R4.1, R11.1, R12.1, U1.6 (V-), U2.11 (V-)
unnamed: C5.1, R7.2
unnamed: C5.2, J1.2
unnamed: C6.1, J2.2
unnamed: C6.2, R8.2, U2.7
unnamed: C7.1, U1.5, U1.7
unnamed: C7.2, RV2.2
unnamed: C8.1, U1.10, U1.12
unnamed: R3.2, RV1.2
unnamed: R4.2, RV1.3
unnamed: R5.1, R7.1, U2.2 (-)
unnamed: R5.2, R16.1, U2.1
unnamed: R6.1, R16.2, U1.4 (-)
unnamed: R9.2, R15.1, U1.13 (-)
unnamed: R10.1, R12.2, R14.1, R15.2, U1.9
unnamed: R8.1, R10.2, U2.6 (-)
unnamed: R6.2, R9.1, R11.2, U1.8
unnamed: R13.1, RV2.3, U2.8
unnamed: R13.2, R14.2, U2.9 (-)
unnamed: RV1.1, U2.13 (-), U2.14
unnamed: J4.2, U2.12 (+)
VCC: C1.1, C3.2, C4.2, J3.2, J4.1, R1.1, U1.11 (V+), U2.4 (V+)
vref: C1.2, C2.1, C8.2, J1.1, J2.1, R1.2, R2.1, RV2.1, U1.3 (+), U1.14 (+), U2.3 (+), U2.5 (+), U2.10 (+)

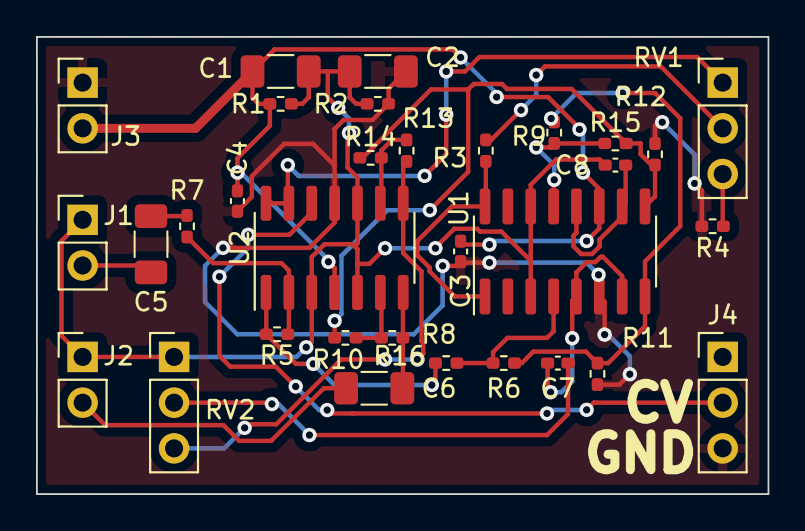
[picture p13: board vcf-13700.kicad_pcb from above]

Board: 2 copper layers, 40.6 x 25.4 mm, 32 parts (0 on the bottom side), 24 nets.

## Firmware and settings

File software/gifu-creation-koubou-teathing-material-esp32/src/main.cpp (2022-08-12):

#include <Arduino.h>
#include <BLEMidi.h>
#include <MozziGuts.h>
#include <mozzi_midi.h>
#include <Oscil.h>  // oscillator template
#include <tables/square_analogue512_int8.h>
#include <tables/saw_analogue512_int8.h>
#include <tables/sin2048_int8.h>
#include <functional>

#include <SoftwareSerial.h>
#include <DFRobotDFPlayerMini.h>

#include <ADSR.h>

#include "IO.h"
#include "FakeTimerInterrupt.h"
#include "SerialUtility.h"

constexpr int SAMPLING_RATE = AUDIO_RATE;

using namespace gifu_creation_koubou_2022_synth;

#define RX (18)
#define TX (19)

DFRobotDFPlayerMini dfPlayer;
gifu_creation_koubou_2022_synth::Io io;

const uint8_t touch_pins[2] = {
    13,
    12,
};

constexpr int kNumInputPins = 4;
const uint8_t in_pins[kNumInputPins] = {
    5,
    17,
    16,
    15,
};

constexpr int kNumAnalogPins = 9;
const uint8_t analog_in_pins[kNumAnalogPins] = {
    0,
    2,
    4,
    14,
    27,
    32,
    33,
    34,
    35,
};

int beat = 0;

struct Transport {
  int bpm = 120;
  bool playing = false;
};
Transport transport;

// unusable analogread pins: 2
// unusable gpio

// modes
enum EditMode {
  kModeSeq,
  kModeEG,
  kModeLFO,
  kNumMode,
};
int mode = kModeSeq;

float getNormalizedFrequency(const int value, const int value_max, const int freq_max) {
  float normalized_freq = io.analogRead(Io::kV1) / (float)value_max;
  normalized_freq *= normalized_freq;
  normalized_freq *= (float)freq_max;

  return normalized_freq;
}

struct Synth {
  int attack = 10;
  int decay = 10;
  int sustain = 100;
  int release = 0;
};
Synth synth;

int raw_knob_values[9] = {-1, -1, -1, -1, -1, -1, -1, -1, -1};
int seq_freqs[8]{
    0,
    0,
    0,
    0,
    0,
    0,
    0,
    0,
};
int seq_step = 0;

class WhiteNoise {
 public:
  WhiteNoise() {}
  int8_t next() {
    return (rand() % 255) - 128;
    ;
  }
};

enum {
  kOscSquare,
  kOscSaw,
  kOscNoise,
};
int osc_type = kOscSquare;

bool touch_amp_enabled = false;
bool touch_lfo_speed_enabled = false;
bool touch_lfo_depth_enabled = false;

ADSR<CONTROL_RATE, AUDIO_RATE> envelope;
Oscil<SQUARE_ANALOGUE512_NUM_CELLS, AUDIO_RATE> squareWave(SQUARE_ANALOGUE512_DATA);
Oscil<SAW_ANALOGUE512_NUM_CELLS, AUDIO_RATE> sawWave(SAW_ANALOGUE512_DATA);
WhiteNoise whiteNoise;

// LFO
Oscil<2048, AUDIO_RATE> lfo1(SIN2048_DATA);
Oscil<2048, AUDIO_RATE> lfo2(SIN2048_DATA);
float lfo1_depth = 0.0;
float lfo2_depth = 0.0;

bool tick_flag = false;
void bpmTick() {
  if (transport.playing) {
    squareWave.setFreq(seq_freqs[seq_step]);
    sawWave.setFreq(seq_freqs[seq_step]);

    envelope.noteOff();
    envelope.noteOn(true);
    seq_step++;
    if (seq_step >= 8) {
      seq_step = 0;
    }
  }

  beat = beat % 4;
  if (beat == 0) {
    tick_flag = true;
    //beat = 0;
  }
  beat++;
}

bool out_value = false;

FakeTimerInterrupt bpmtick(SAMPLING_RATE);

SoftwareSerial swSer(RX, TX);

void setMode(const int new_mode) {
  mode = new_mode;
  io.digitalWrite(Io::kModeLFOLed, LOW);
  io.digitalWrite(Io::kModeEGLed, LOW);
  io.digitalWrite(Io::kModeSeqLed, LOW);
  switch (mode) {
    case kModeSeq:
      Serial.println("seq");
      io.digitalWrite(Io::kModeSeqLed, HIGH);

      break;
    case kModeEG:
      Serial.println("eg");
      io.digitalWrite(Io::kModeEGLed, HIGH);
      break;
    case kModeLFO:
      Serial.println("lfo");
      io.digitalWrite(Io::kModeLFOLed, HIGH);
      break;
  }
}

// switch callbacks
void onSwitchPlay(const int low_hi) {
  p("onSwitchPlay\n");
  transport.playing = !transport.playing;
  if (!transport.playing) {
    p("noteoff\n");
    envelope.noteOff();
  }

  if (transport.playing) {
    beat = 0;
    seq_step = 0;
    bpmTick();
  }

  bpmtick.start();
  io.digitalWrite(Io::kPlayLed, transport.playing);
}

int last_freq = 1000;
void onSwitchTrigger(const int low_hi) {
  p("onSwitchTrigger, low_hi = %d\n", low_hi);

  if (!low_hi) {
    squareWave.setFreq(seq_freqs[0]);
    sawWave.setFreq(seq_freqs[0]);
    envelope.noteOn();

  } else {
    envelope.noteOff();
  }
  io.digitalWrite(Io::kTriggerLed, !low_hi);
}

void onSwitchMode(const int low_hi) {
  p("onSwitchMode\n");
  auto newMode = mode + 1;
  if (newMode >= kNumMode) {
    newMode = 0;
  }
  setMode(newMode);
}

bool audioPlayerPlaying = false;
void onSwitchAudioPlayer(const int low_hi) {
  p("onSwitchAudioPlayer\n");
  audioPlayerPlaying = !audioPlayerPlaying;
  if (audioPlayerPlaying) {
    dfPlayer.loop(1);
    io.digitalWrite(Io::kAudioPlayerLed, HIGH);
  } else {
    dfPlayer.stop();
    io.digitalWrite(io.kAudioPlayerLed, LOW);
  }
}  // sw4

void selectOsc() {
  if (!io.digitalReadMcp(Io::kMcpPinPatchSaw)) {
    osc_type = kOscSaw;
  } else if (!io.digitalReadMcp(Io::kMcpPinPatchNoise)) {
    osc_type = kOscNoise;
  } else {  // dafaulting to square
    osc_type = kOscSquare;
  }
  p("osc_type = %d\n", osc_type);
}
void onPatchSaw(const int low_hi) {
  p("onPatchSaw\n");
  selectOsc();
}

void onPatchSquare(const int low_hi) {
  p("onPatchSquare\n");
  selectOsc();
}

void onPatchNoise(const int low_hi) {
  p("onPatchNoise\n");
  selectOsc();
}

void onPatchTouchAmp(const int low_hi) {
  touch_amp_enabled = !low_hi;
  p("touch_amp_enabled = %d\n", touch_amp_enabled);
}
void onPatchTouchLFOSpeed(const int low_hi) {
  touch_lfo_speed_enabled = !low_hi;
  p("touch_lfo_speed_enabled = %d\n", touch_lfo_speed_enabled);
}
void onPatchTouchLFODepth(const int low_hi) {
  touch_lfo_depth_enabled = !low_hi;
  p("touch_lfo_depth_enabled = %d\n", touch_lfo_depth_enabled);
}

void setup() {
  Serial.begin(115200);
  swSer.begin(9600);

  Serial.println("Hello!");

  io.inputChangeCallbacks[Io::kSwitchPlay] = onSwitchPlay;
  io.inputChangeCallbacks[Io::kSwitchTrigger] = onSwitchTrigger;
  io.inputChangeCallbacks[Io::kSwitchMode] = onSwitchMode;
  io.inputChangeCallbacks[Io::kSwitchAudioPlayer] = onSwitchAudioPlayer;

  // patching
  io.inputChangeCallbacks[Io::kPatchSaw] = onPatchSaw;
  io.inputChangeCallbacks[Io::kPatchSquare] = onPatchSquare;
  io.inputChangeCallbacks[Io::kPatchNoise] = onPatchNoise;

  io.inputChangeCallbacks[Io::kPatchTouchAmp] = onPatchTouchAmp;
  io.inputChangeCallbacks[Io::kPatchTouchLFOSpeed] = onPatchTouchLFOSpeed;
  io.inputChangeCallbacks[Io::kPatchTouchLFODepth] = onPatchTouchLFODepth;
  io.setup();

  setMode(kModeSeq);

  for (auto i = 0; i < 5; i++) {
    if (dfPlayer.begin(swSer)) {
      break;
      delay(500);
    }
  }

  Serial.println(F("DFPlayer Mini online."));
  dfPlayer.reset();
  dfPlayer.volume(30);

  delay(1000);

  startMozzi(CONTROL_RATE);
  squareWave.setFreq(1000);
  sawWave.setFreq(1000);

  envelope.setAttackTime(0);
  envelope.setAttackLevel(255);
  envelope.setDecayLevel(255);
  envelope.setReleaseLevel(1);
  envelope.setDecayTime(0);
  envelope.setSustainLevel(255);
  envelope.setSustainTime(UINT32_MAX);
  envelope.setReleaseTime(0);
  bpmtick.setCallback(bpmTick);

  bpmtick.setCallback(bpmTick);
  bpmtick.setIntervalMsec(250);
}

auto last_analog_value = 0;
uint8_t last_touch_value[2] = {0, 0};
bool onOff = false;
void setSeqFreq(const int index, const int freq) {
  if (index >= 8) {
    return;
  }

  seq_freqs[index] = freq;
}
int analog_read_index = 0;
void updateControl() {
  envelope.update();
  io.scanInput();
  last_touch_value[0] = io.getTouch(Io::TouchPinId::kTouch0);
  last_touch_value[1] = io.getTouch(Io::TouchPinId::kTouch1);
  if (touch_lfo_speed_enabled) {
    const auto lfo_freq = last_touch_value[0] >> 2;
    lfo1.setFreq(lfo_freq);
  }
  if (touch_lfo_depth_enabled) {
    lfo1_depth = last_touch_value[1] / 127.0;
  }
  io.digitalWrite(Io::kBpmLed, tick_flag);
  if (tick_flag) {
    tick_flag = 0;
  }

  auto value = io.analogRead(analog_read_index) >> 5;
  if (analog_read_index == 0) {
    value = map(value, 19, 127, 0, 127);
  }
  if (value != raw_knob_values[analog_read_index]) {
    raw_knob_values[analog_read_index] = value;
    //p("raw_knob_values[%d] = %d\n", i, value);
    switch (mode) {
      case kModeSeq: {
        const auto freq = mtof(value);
        setSeqFreq(analog_read_index, freq);
        if (!transport.playing) {
          const auto freq = mtof(raw_knob_values[0]);
          squareWave.setFreq(freq);
          sawWave.setFreq(freq);
          last_freq = freq;
        }
      } break;
      case kModeEG: {
        if (analog_read_index == 0) {
          const auto attack = value << 5;
          p("attack = %d\n", attack);
          envelope.setAttackTime(attack);
        }
        if (analog_read_index == 1) {
          const auto decay = value << 5;
          p("decay = %d\n", decay);
          envelope.setDecayTime(value << 5);
        }
        if (analog_read_index == 2) {
          const auto sustain = value << 1;
          p("sustain = %d\n", sustain);
          envelope.setDecayLevel(sustain);
          envelope.setSustainLevel(sustain);
        }
        if (analog_read_index == 3) {
          const auto release = value << 5;
          envelope.setReleaseTime(release);
        }

      } break;
      case kModeLFO:
        if (analog_read_index == 0) {
          if (!touch_lfo_speed_enabled) {
            const auto lfo_freq = value >> 2;
            p("lfo_freq = %d\n", lfo_freq);
            lfo1.setFreq(lfo_freq);
          }
        }
        if (analog_read_index == 1) {
          if (!touch_lfo_depth_enabled) {
            lfo1_depth = value / 127.0;
            p("lfo_depth = %f\n", lfo1_depth);
          }
        }
        if (analog_read_index == 2) {
          const auto lfo2_freq = value >> 2;
          p("lfo2_freq = %d\n", lfo2_freq);
          lfo2.setFreq(lfo2_freq);
        }
        if (analog_read_index == 3) {
          lfo2_depth = value / 127.0;
          p("lfo2_depth = %f\n", lfo2_depth);
        }
        break;
      default:
        break;

        // update triggered pitch
    }

    // update bpm
    if (analog_read_index == 8) {
      auto bpm = io.analogRead(Io::kV9) >> 5;
      bpm = map(bpm, 0, 4096 >> 5, 30, 240);
      const auto absDelta = abs(bpm - transport.bpm);
      if (absDelta >= 2) {
        transport.bpm = bpm;
        bpmtick.setIntervalMsec(60000 / transport.bpm / 4);
        //p("BPM: %d\n", transport.bpm);
      }
    }
  }
  analog_read_index++;
  analog_read_index = analog_read_index % 9;
}

int8_t AM_modulate(int8_t carrier, int8_t modulation, int8_t depth) {
  if (depth < 1) {
    return carrier;
  }
  int16_t sample = (int16_t)carrier;                    // carrier is signed
  uint16_t am = (uint16_t)((int16_t)modulation + 128);  // unsigned modulation 0..255
  uint16_t dp = (uint16_t)((int16_t)depth + 128);       // unsigned depth 0..255

  return (int8_t)((sample * (((am * dp) >> 8) + (255 - dp))) >> 8);
}
int updateAudio() {
  auto get_output = [](Q15n16 pitch_mod) -> int8_t {
    switch (osc_type) {
      case kOscSaw:
        return sawWave.phMod(pitch_mod);
      case kOscNoise:
        return whiteNoise.next();
      case kOscSquare:  // FALLTHRU
      default:
        return squareWave.phMod(pitch_mod);
    }
  };
  bpmtick.tick();
  Q15n16 pitch_lfo_out = (Q15n16)(lfo2.next() * ((int)(lfo2_depth * 255)));

  auto out = get_output(pitch_lfo_out);
  if (touch_amp_enabled) {
    out = (out * last_touch_value[0]) >> 7;
  }

  auto lfo1_out = lfo1.next();
  auto am_modulated = AM_modulate(out, lfo1_out, (int)(lfo1_depth * 127));
  return (int)(envelope.next() * am_modulated) >> 8;
}

void loop() {
  audioHook();
}

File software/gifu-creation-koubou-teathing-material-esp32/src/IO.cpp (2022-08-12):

/**
 * @file IO.cpp
 * @brief
 *
 * @author Kazuki Saita <saita@kinoshita-lab.com>
 *
 * Copyright (c) 2022 Kinoshita Lab. All rights reserved.
 *
 */
#include "IO.h"
#include <Arduino.h>
#include <MozziGuts.h>
#include "SerialUtility.h"
#include "Bounce2mcp.h"
#include "Bounce2.h"

namespace gifu_creation_koubou_2022_synth {

BounceMcp mcp_debouncers[Io::kNumMcpInputPinId] = {
    BounceMcp(),
    BounceMcp(),
    BounceMcp(),
    BounceMcp(),

    BounceMcp(),
    BounceMcp(),
    BounceMcp(),
    BounceMcp(),

};

Bounce2::Button bouncers[Io::kNumEspInputPinId] = {
    Bounce2::Button(),
    Bounce2::Button(),
    Bounce2::Button(),
    Bounce2::Button(),
};

const uint8_t Io::touch_pins[(int)TouchPinId::kNumTouch] = {T5, T4};
const uint8_t Io::esp_input_pins[(int)Io::EspInputPinId::kNumEspInputPinId]{
    5,
    17,
    16,
    15,
};

const uint8_t Io::analog_pins[Io::kNumAnalogPins]{
    0,
    2,
    4,
    14,
    27,
    32,
    33,
    34,
    35,
};

Io::Io() {}

void Io::setup() {
  p("Io::setup()");
  // initialize mcp
  if (!mcp.begin_I2C()) {
    Serial.println("MCP23X17 not found");
    while (true) {
      delay(1000);
      Serial.println("MCP23X17 not found");
    }
  } else {
    Serial.println("MCP23X17 found");
  }

  // initialize ESP32 pins
  for (int i = 0; i < kNumEspInputPinId; i++) {
    pinMode(esp_input_pins[i], INPUT_PULLUP);
    bouncers[i].attach(esp_input_pins[i], INPUT_PULLUP);
    bouncers[i].interval(5);
    bouncers[i].setPressedState(LOW);
  }

  // initialize mcp
  for (auto i = 0; i < kNumMCPOutput; ++i) {
    mcp.pinMode(i + 8, OUTPUT);
    mcp.digitalWrite(i, LOW);
    output_buffers = 0;
    mcp.writeGPIOB(output_buffers);
  }
  for (auto i = 0; i < kNumMCPInput; ++i) {
    mcp.pinMode(i, INPUT_PULLUP);
  }
  // attach bouncers for mcp
  for (auto i = 0; i < kNumMcpInputPinId; ++i) {
    mcp_debouncers[i].attach(mcp, i, 5);
  }

  // read and emit input status
  for (auto i = 0; i < kNumMcpInputPinId; ++i) {
    const auto pin_value = mcp.digitalRead(i);
    const auto id = mcpPin2Id(i);
    if (inputChangeCallbacks[id]) {
      if (pin_value == HIGH) {
        if (shouldMcpInputCheckRose(i)) {
          inputChangeCallbacks[id](HIGH);
        }
      } else {
        inputChangeCallbacks[id](LOW);
      }
    }
  }

  // set average value to touch pins
  touchSetCycles(0x1000 >> 5, 0x1000 >> 1);
  auto averageInput = [&](const uint8_t touch_pin) -> int {
    auto sum = 0;
    auto loop_times = 100;
    for (auto i = 0; i < loop_times; ++i) {
      sum += touchRead((int)touch_pin);
    }
    return sum / loop_times;
  };
  touch_average[(int)TouchPinId::kTouch0] = averageInput(touch_pins[(int)TouchPinId::kTouch0]);
  touch_average[(int)TouchPinId::kTouch1] = averageInput(touch_pins[(int)TouchPinId::kTouch1]);

  p("touch_average[%d] = %d\n", (int)TouchPinId::kTouch0, touch_average[(int)TouchPinId::kTouch0]);
  p("touch_average[%d] = %d\n", (int)TouchPinId::kTouch1, touch_average[(int)TouchPinId::kTouch1]);
}

int Io::getTouch(const TouchPinId id) {
  const uint8_t read = touchRead((int)touch_pins[(int)id]);
  const auto limited = std::min(touch_average[(int)id], read);
  const auto mapped = map(limited, 0, touch_average[(int)id], 127, 0);

  return mapped;
}

void Io::scanInput() {
  // scan mcp
  for (auto i = 0; i < kNumMcpInputPinId; ++i) {
    mcp_debouncers[i].update();
    const auto id = mcpPin2Id(i);
    if (mcp_debouncers[i].fell()) {
      if (id != -1) {
        if (inputChangeCallbacks[id])
          inputChangeCallbacks[id](LOW);
      }
    }
    if (shouldMcpInputCheckRose(i)) {
      if (id != 1) {
        if (mcp_debouncers[i].rose()) {
          if (inputChangeCallbacks[id])
            inputChangeCallbacks[id](HIGH);
        }
      }
    }
  }

  for (auto i = 0; i < kNumEspInputPinId; ++i) {
    bouncers[i].update();
    const auto id = espPin2Id(i);
    if (bouncers[i].fell()) {
      if (id != -1) {
        if (inputChangeCallbacks[id])
          inputChangeCallbacks[id](LOW);
      }
    }
    if (i == kEspPinSwitchTrigger) {
      if (bouncers[i].rose()) {
        if (inputChangeCallbacks[id])
          inputChangeCallbacks[id](HIGH);
      }
    }
  }
}

int Io::digitalReadMcp(const int pin) {
  return mcp.digitalRead(pin);
}
void Io::digitalWrite(const int pin, int value) {
  if (value) {
    output_buffers |= (1 << pin);
  } else {
    output_buffers &= ~(1 << pin);
  }
  mcp.writeGPIOB(output_buffers);
}
int Io::analogRead(const int index) {
  auto sum = 0.f;
  for (auto i = 0; i < 5; ++i) {
    sum += mozziAnalogRead(analog_pins[index]);
  }
  return sum / 5;
}

}  // namespace gifu_creation_koubou_2022_synth

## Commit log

2022-08-12 add hardware design file
    [gifu-creation-koubou.kicad_pcb, gifu-creation-koubou.kicad_sch]
2022-08-12 add software material as-is
2022-08-22 reorganize folder structure, add module circuits
    [PT2399delay.kicad_pcb, PT2399delay.kicad_sch, gifu-creation-koubou.kicad_pcb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]
